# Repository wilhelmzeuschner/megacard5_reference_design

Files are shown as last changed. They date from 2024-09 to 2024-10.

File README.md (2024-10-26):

# Reference Design for MegaCard 5 Carrier Board
**Further documentation avaiable at: www.wizeus.de/megacard5-docs**
Reference design for the MegaCard 5 100 Mbit/s Ethernet Switch Carrier Board.

The design is done in KiCad. All KiCad files are included in this repo.

## PDF Schematic
The pdf schematic is available here: https://github.com/wilhelmzeuschner/megacard5_reference_design/blob/main/doc/megacard5_reference_design.pdf

## PCB images




Please note that the picture shows Rev. 1.0 of the PCB. The render shows Rev. 1.1.

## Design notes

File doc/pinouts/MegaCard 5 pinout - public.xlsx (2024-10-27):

MegaCard 5 Top Side Pins |  |  | MegaCard 5 Bottom Side Pins
Pin number | Function | Note | Pin number | Function | Note
1 | GND |  | 2 | GND
3 | PWR_IN | Power input | 4 | !RESET | ETH switch IC reset signal (active low, can be left floating)
5 | PWR_IN | Power input | 6 | !POWER_OFF | ETH switch IC power down signal (active low, can be left floating)
7 | GND |  | 8 | GND
9 | 5V_OUT | 5 V output / input | 10 | RESERVED | Don't connect on host PCB
11 | 5V_OUT | 5 V output / input | 12 | SCL/MDC | Optional configuration interface clock signal
13 | 3.3V_OUT | 3.3 V output / input | 14 | SDA/MDIO | Optional configuration interface data signal
15 | GND |  | 16 | GND
MegaCard 5 Alignment slot in PCB / Connector |  |  | MegaCard 5 Alignment slot in PCB / Connector
17 | RESERVED | Don't connect on host PCB | 18 | RESERVED | Don't connect on host PCB
19 | RESERVED | Don't connect on host PCB | 20 | RESERVED | Don't connect on host PCB
21 | GND |  | 22 | GND
23 | P0_RX+ |  | 24 | P3_RX+
25 | P0_RX- |  | 26 | P3_RX-
27 | GND |  | 28 | GND
29 | P0_TX+ |  | 30 | P3_TX+
31 | P0_TX- |  | 32 | P3_TX-
33 | GND |  | 34 | GND
35 | P1_RX+ |  | 36 | P4_RX+
37 | P1_RX- |  | 38 | P4_RX-
39 | GND |  | 40 | GND
41 | P1_TX+ |  | 42 | P4_TX+
43 | P1_TX- |  | 44 | P4_TX-
45 | GND |  | 46 | GND
47 | P2_RX+ |  | 48 | P2_TX+
49 | P2_RX- |  | 50 | P2_TX-
51 | GND |  | 52 | GND
 |  |  |  |  |  | https://www.te.com/commerce/DocumentDelivery/DDEController?Action=showdoc

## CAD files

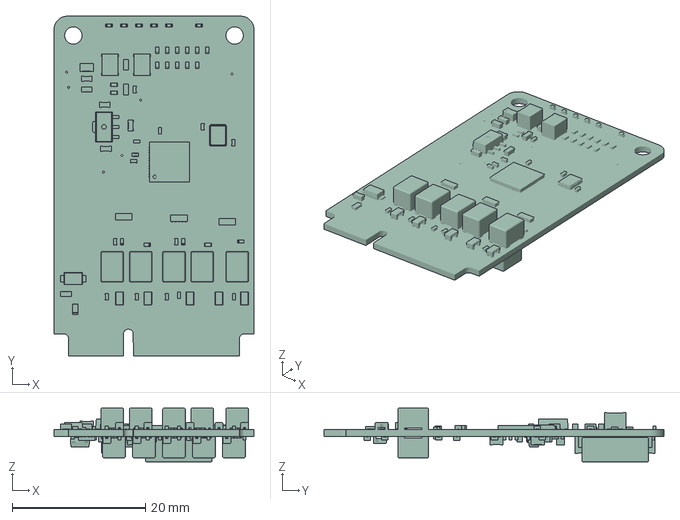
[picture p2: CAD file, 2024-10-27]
cad/MegaCard 5 3D printable model.3mf
30.0 x 51.0 x 8.09 mm

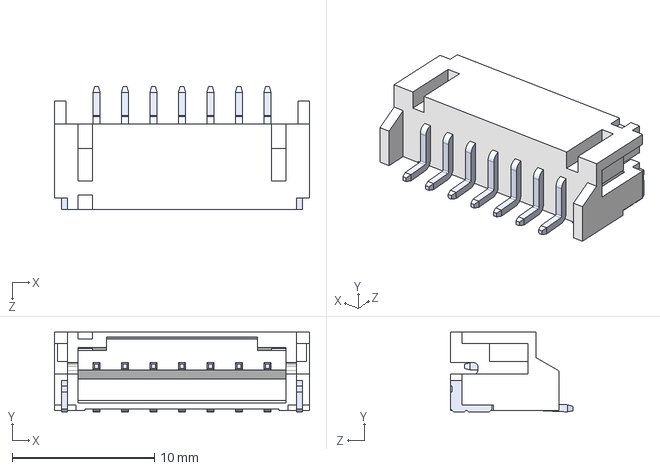
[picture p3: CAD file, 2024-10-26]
pcb/kicad_3d_models/S7B-PH-SM4-TB.STEP
17.9 x 5.60 x 8.60 mm

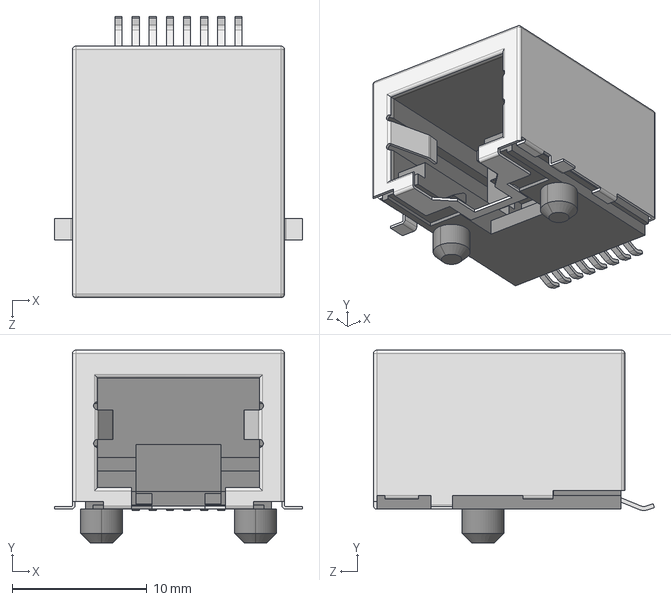
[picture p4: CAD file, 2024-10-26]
pcb/kicad_3d_models/MJ88-B211-JRS3.step
18.4 x 14.3 x 20.9 mm

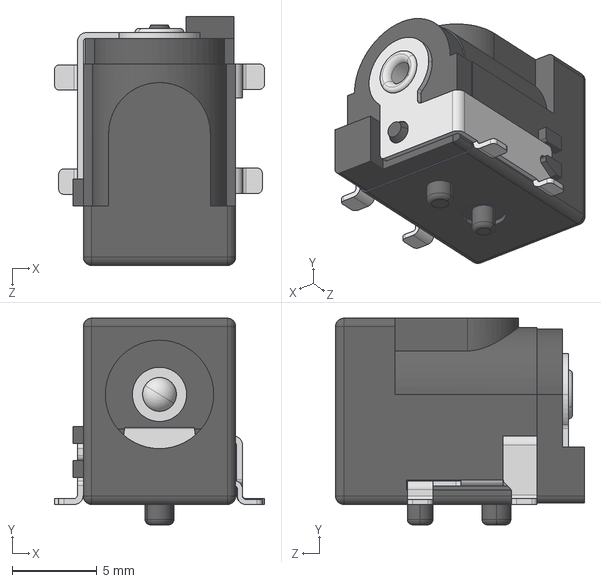
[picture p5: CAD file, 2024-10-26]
pcb/kicad_3d_models/DC-005-5A-2-0-SMT.step
12.4 x 12.2 x 14.7 mm

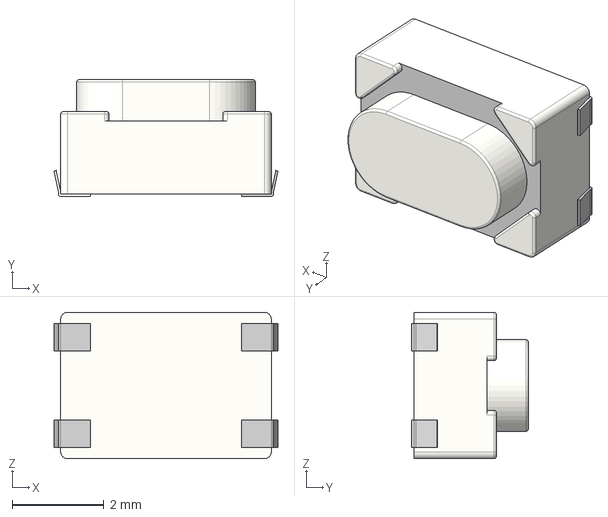
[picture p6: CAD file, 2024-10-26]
pcb/kicad_3d_models/SKRPAC.STEP
4.89 x 2.55 x 3.20 mm

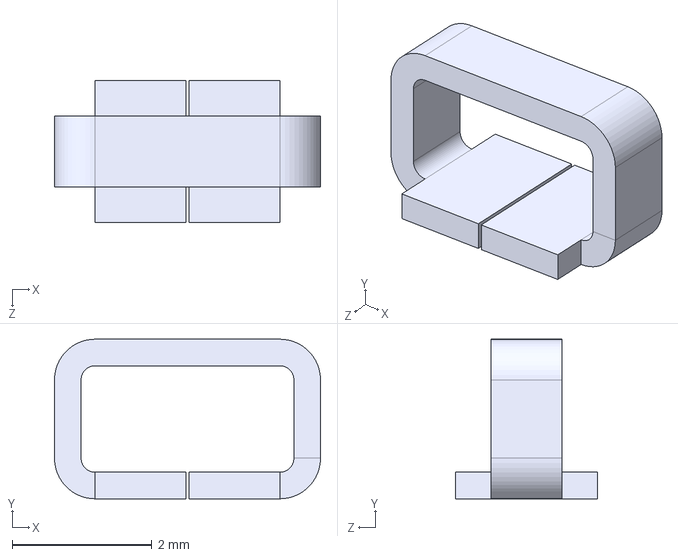
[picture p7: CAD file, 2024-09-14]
pcb/kicad_3d_models/5019.step
3.81 x 2.29 x 2.03 mm

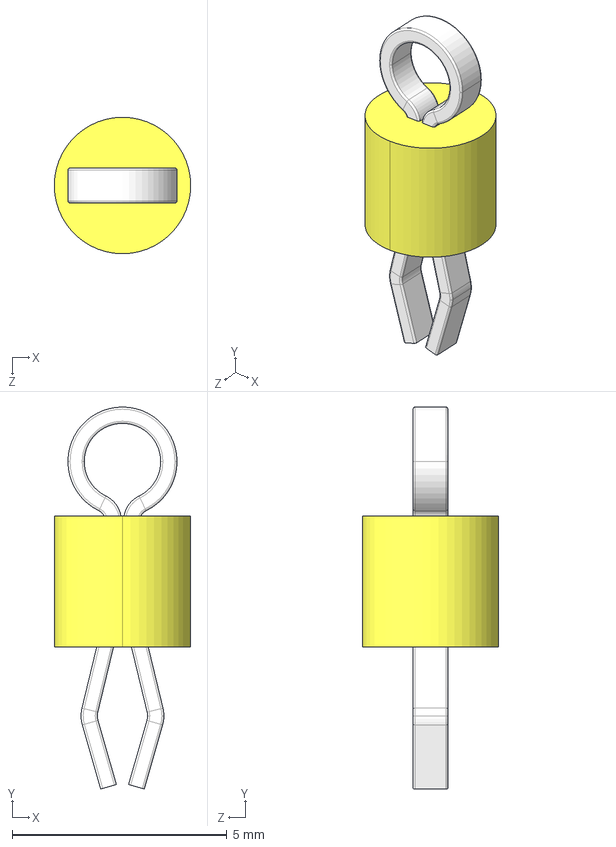
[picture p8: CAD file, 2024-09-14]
pcb/kicad_3d_models/5009.step
3.17 x 8.89 x 3.17 mm

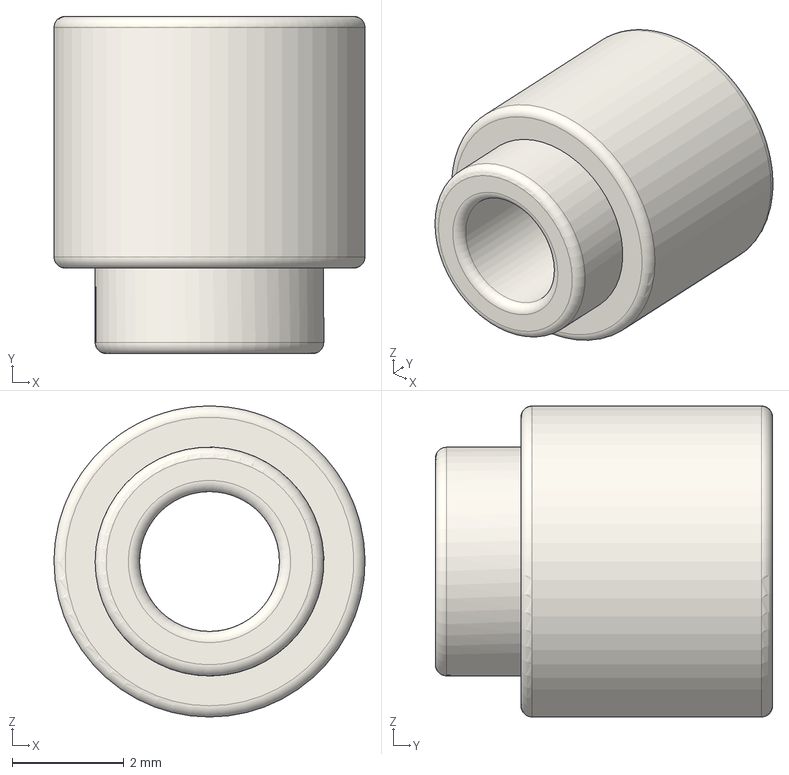
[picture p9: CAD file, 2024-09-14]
pcb/kicad_3d_models/SMTSO2545CTJ.step
5.56 x 6.03 x 5.56 mm

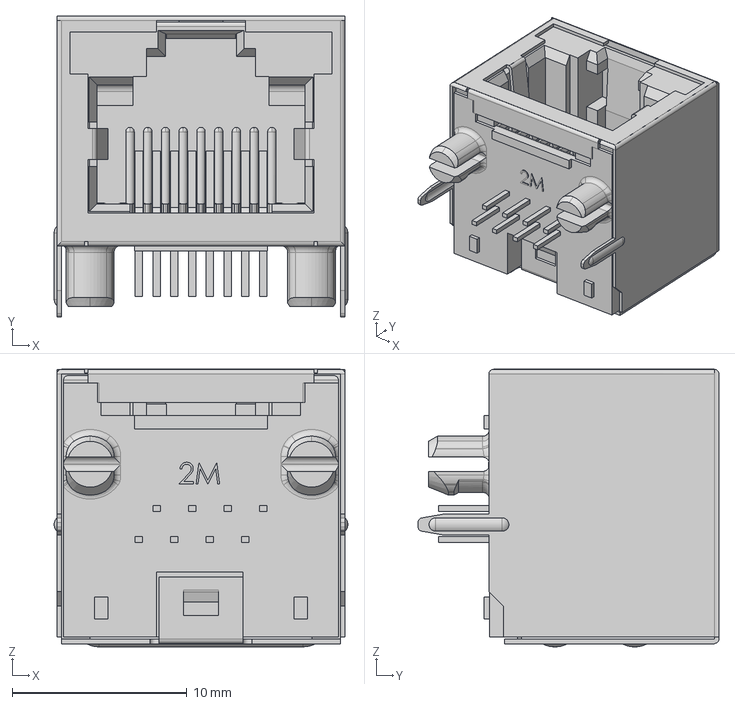
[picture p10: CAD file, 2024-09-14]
pcb/kicad_3d_models/ethernet_connector.STEP
16.8 x 17.2 x 15.9 mm

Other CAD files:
pcb/kicad_3d_models/5007.step
pcb/kicad_3d_models/5006.step
pcb/kicad_3d_models/5005.step

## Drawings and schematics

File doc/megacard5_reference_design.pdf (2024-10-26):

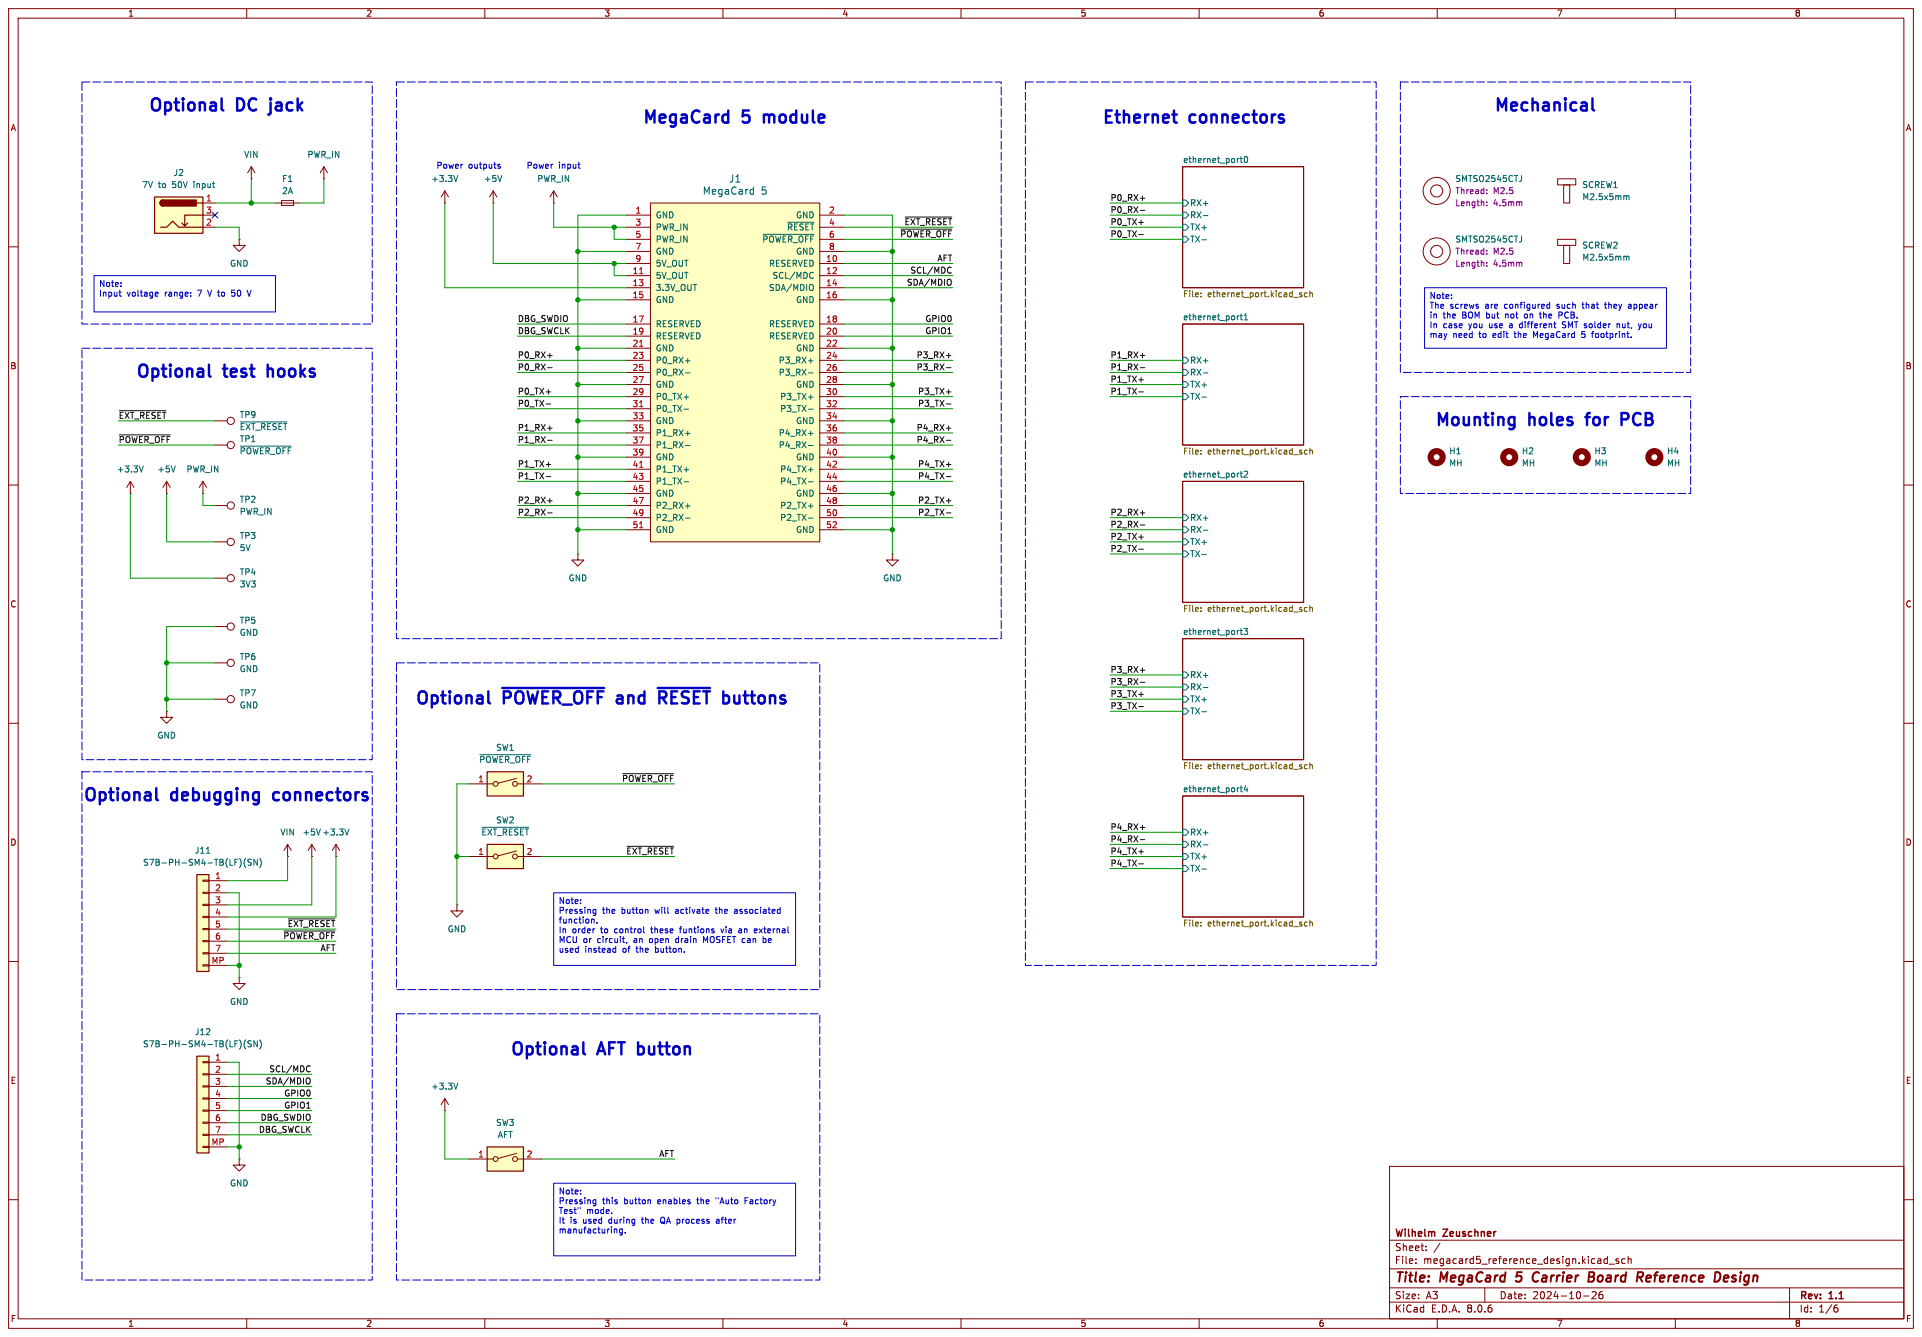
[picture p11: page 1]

Mechanical Ethernet connectors
TX+ TX- RX+ RX- ethernet_port0 File: ethernet_port.kicad_sch TX+ TX- RX+ RX- ethernet_port1 File: ethernet_port.kicad_sch TX+ TX- RX+ RX- ethernet_port2 File: ethernet_port.kicad_sch TX+ TX- RX+ RX- ethernet_port4 File: ethernet_port.kicad_sch TX+ TX- RX+ RX- ethernet_port3 File: ethernet_port.kicad_sch

in the BOM but not on the PCB.

Mounting holes for PCB

Optional ~{POWER_OFF}and ~{RESET}buttons

J11 S7B-PH-SM4-TB(LF)(SN) GND

used instead of the button. Note: Pressing this button enables the "Auto Factory Test" mode.

SCL/MDC GPIO1 SDA/MDIO

It is used during the QA process after manufacturing.

File: megacard5_reference_design.kicad_sch Sheet: / Wilhelm Zeuschner

Id: 1/6 Title: MegaCard 5 Carrier Board Reference Design

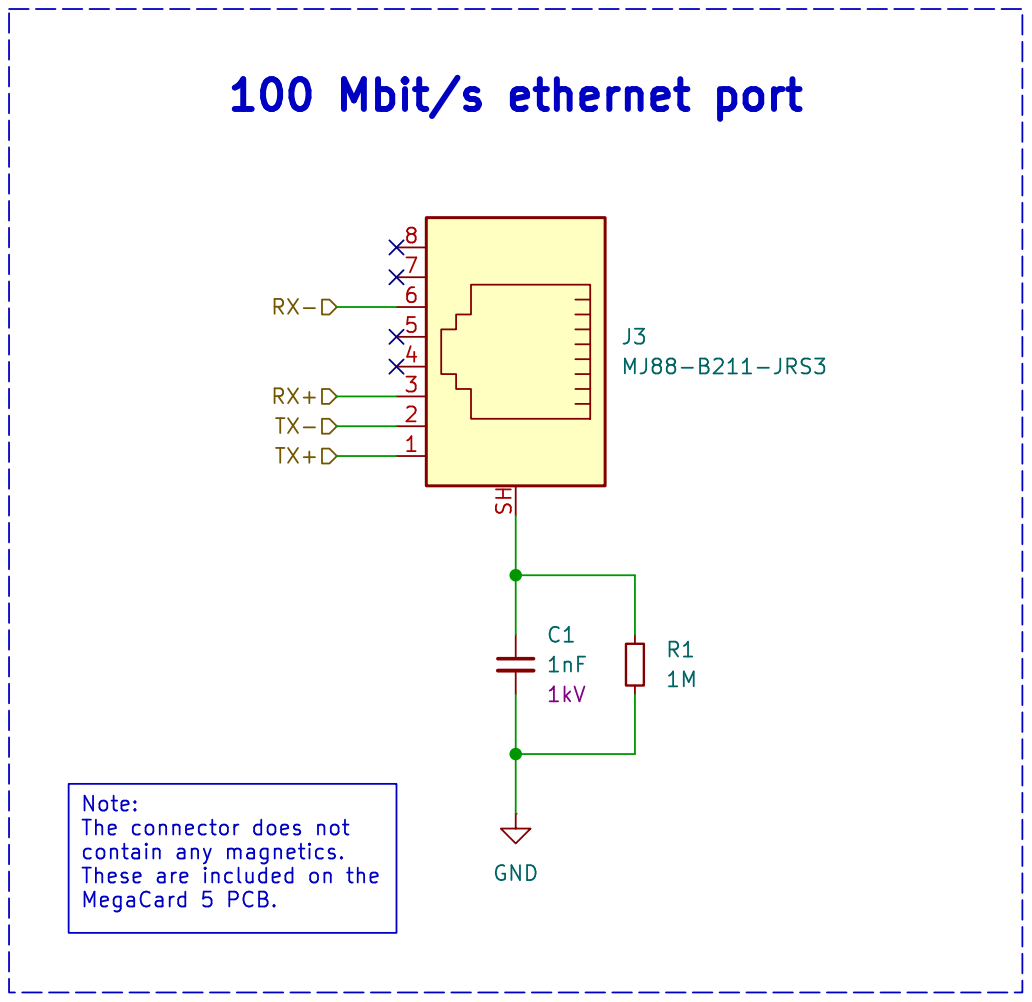
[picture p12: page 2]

Id: 2/6 Title: Ethernet port File: ethernet_port.kicad_sch Sheet: /ethernet_port0/ Wilhelm Zeuschner

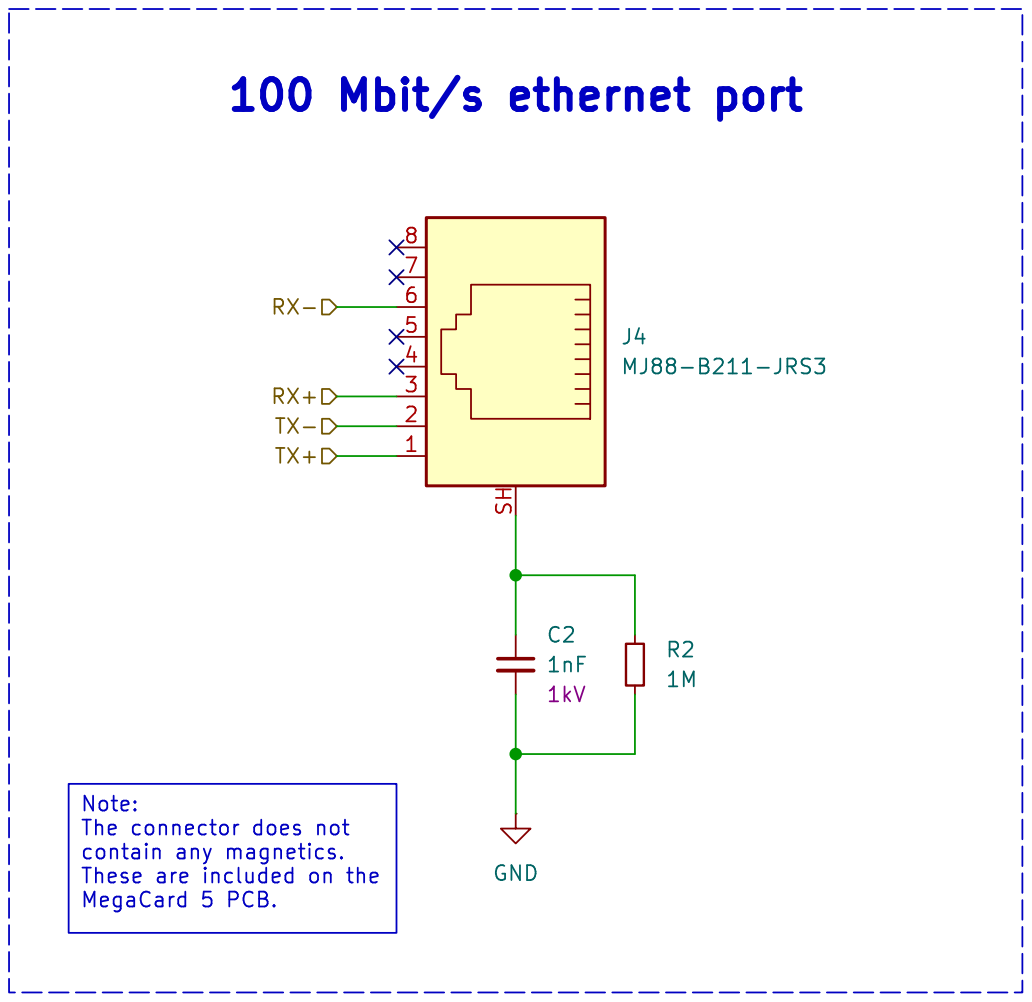
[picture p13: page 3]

Id: 3/6 Title: Ethernet port File: ethernet_port.kicad_sch Sheet: /ethernet_port1/ Wilhelm Zeuschner

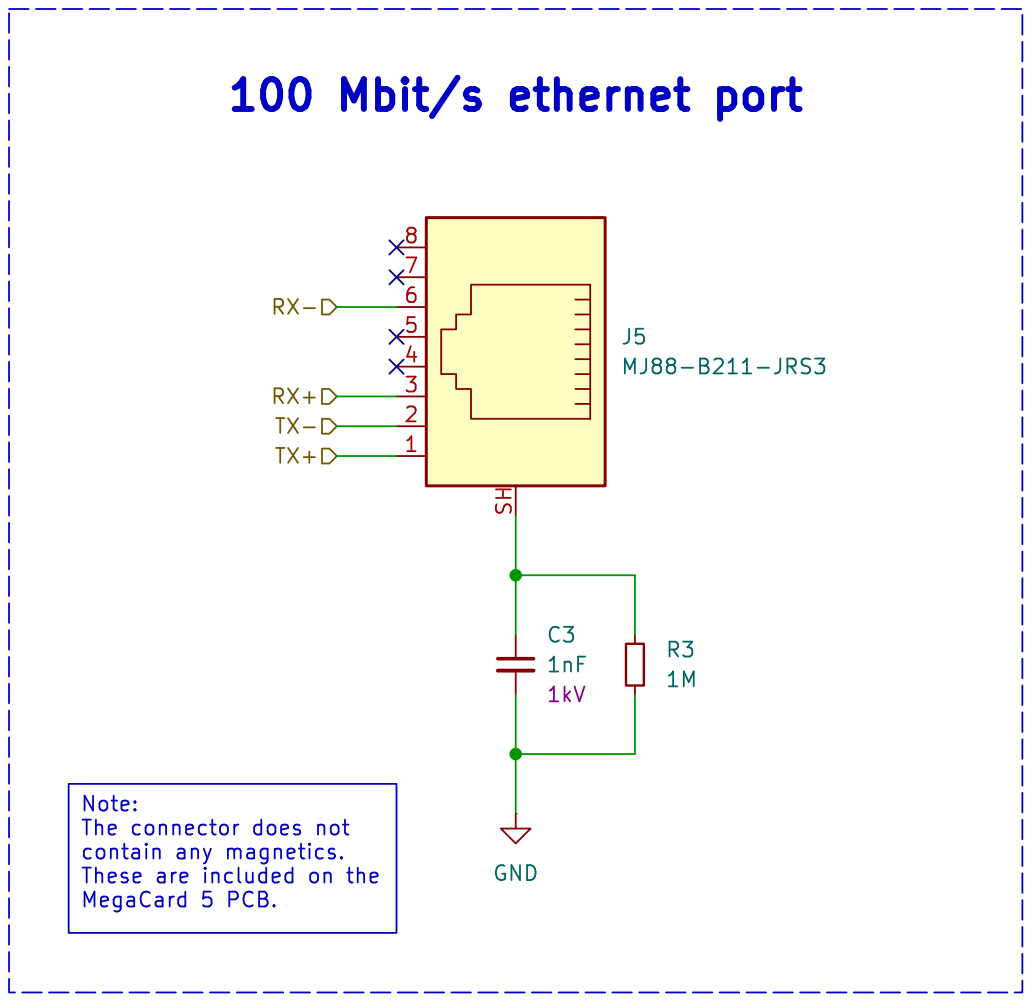
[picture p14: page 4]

Id: 4/6 Title: Ethernet port File: ethernet_port.kicad_sch Sheet: /ethernet_port2/ Wilhelm Zeuschner

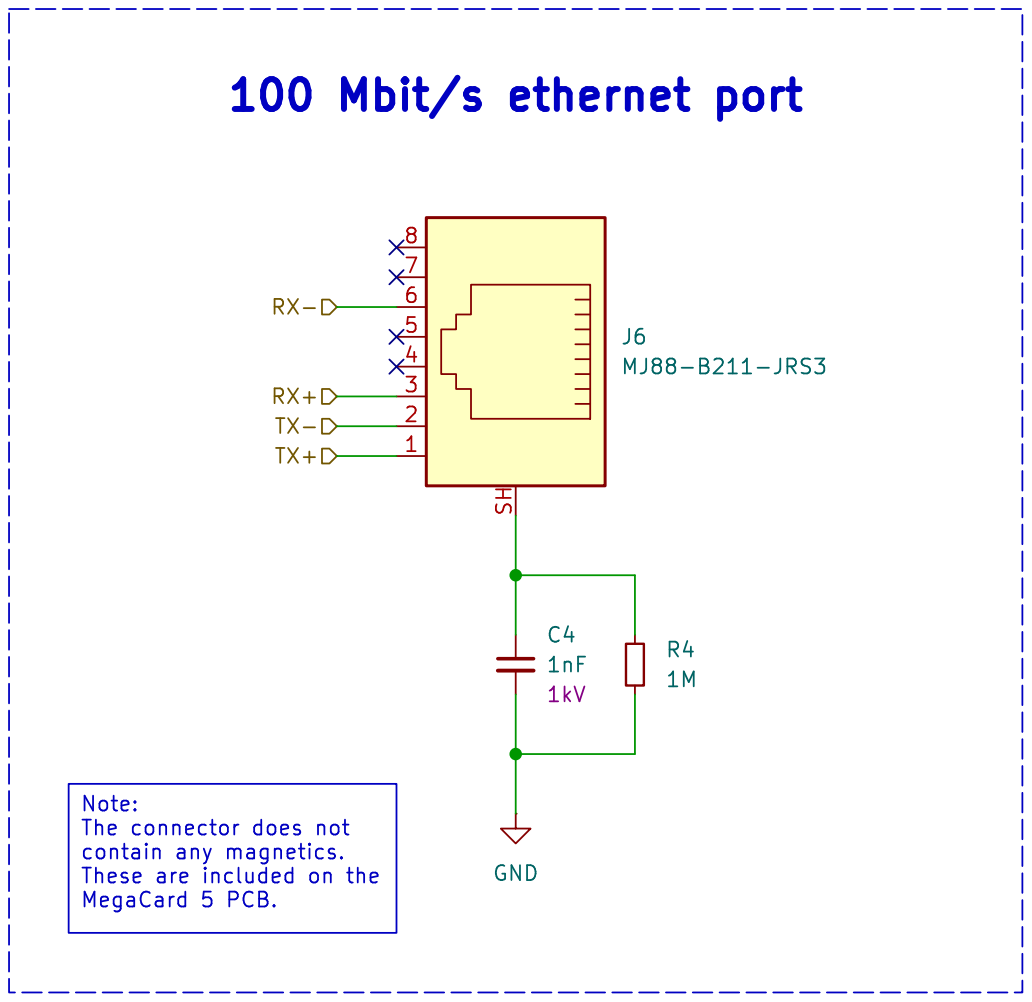
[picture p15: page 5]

Id: 5/6 Title: Ethernet port File: ethernet_port.kicad_sch Sheet: /ethernet_port3/ Wilhelm Zeuschner

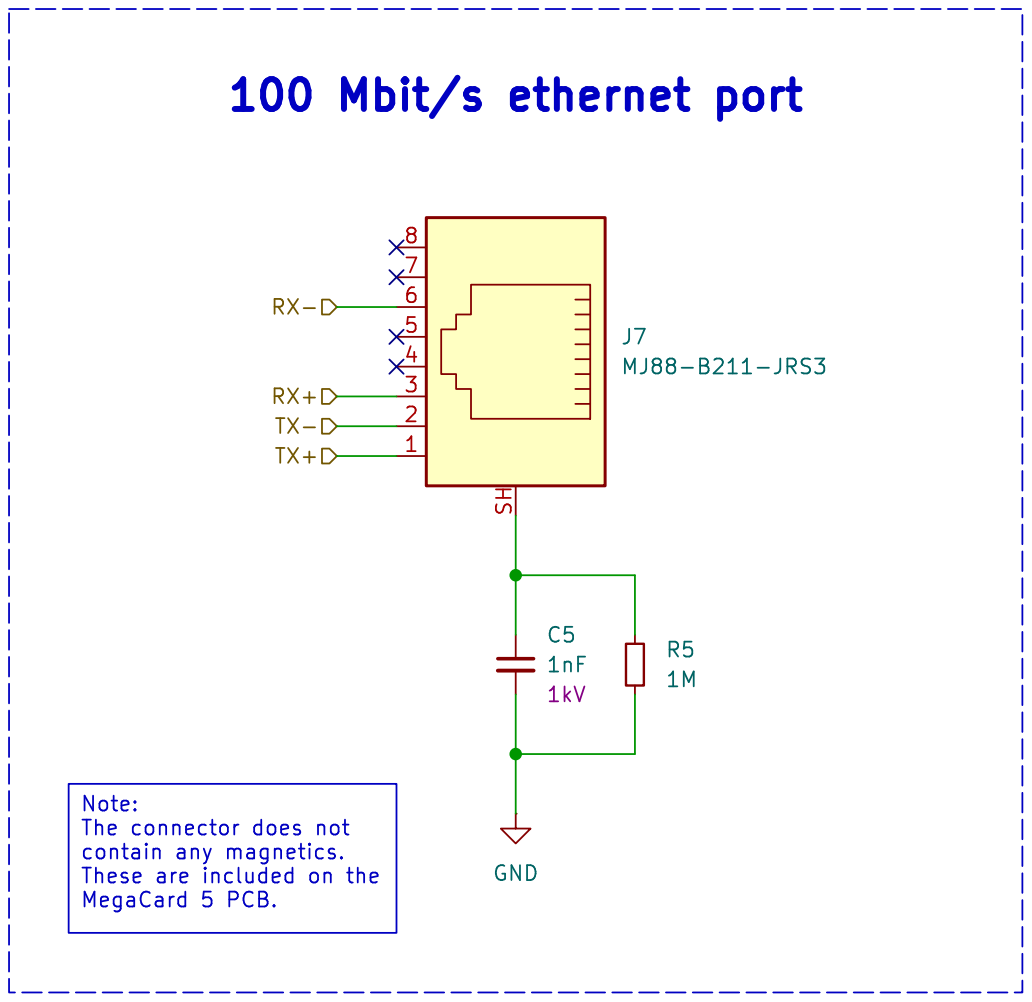
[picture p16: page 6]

Id: 6/6 Title: Ethernet port File: ethernet_port.kicad_sch Sheet: /ethernet_port4/ Wilhelm Zeuschner

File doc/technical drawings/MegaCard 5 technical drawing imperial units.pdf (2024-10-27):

# Bottom view

# 1.18in 2.01in 1.88in 0.04in⁺⁰.05in -0in

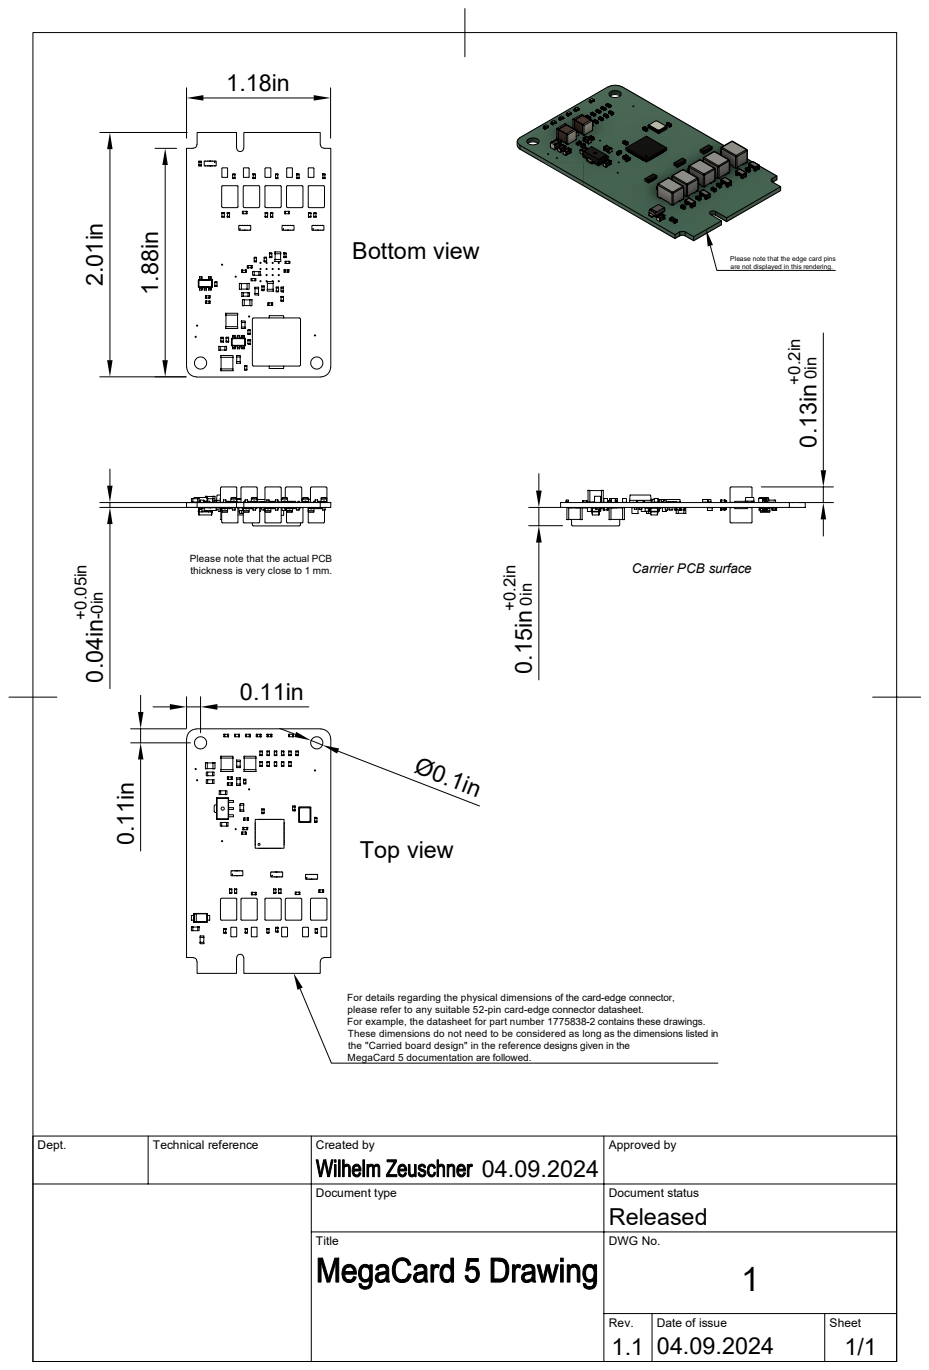
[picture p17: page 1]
Dept.; Technical reference; Created by; Approved by; Document type; Document status; Title; DWG No.; Rev.; Date of issue; Sheet; Released; Top view

Please note that the edge card pins
are not displayed in this rendering.

Please note that the actual PCB
thickness is very close to 1 mm.

Carrier PCB surface

For details regarding the physical dimensions of the card-edge connector,
please refer to any suitable 52-pin card-edge connector datasheet.
For example, the datasheet for part number 1775838-2 contains these drawings.
These dimensions do not need to be considered as long as the dimensions listed in
the "Carried board design" in the reference designs given in the
MegaCard 5 documentation are followed.

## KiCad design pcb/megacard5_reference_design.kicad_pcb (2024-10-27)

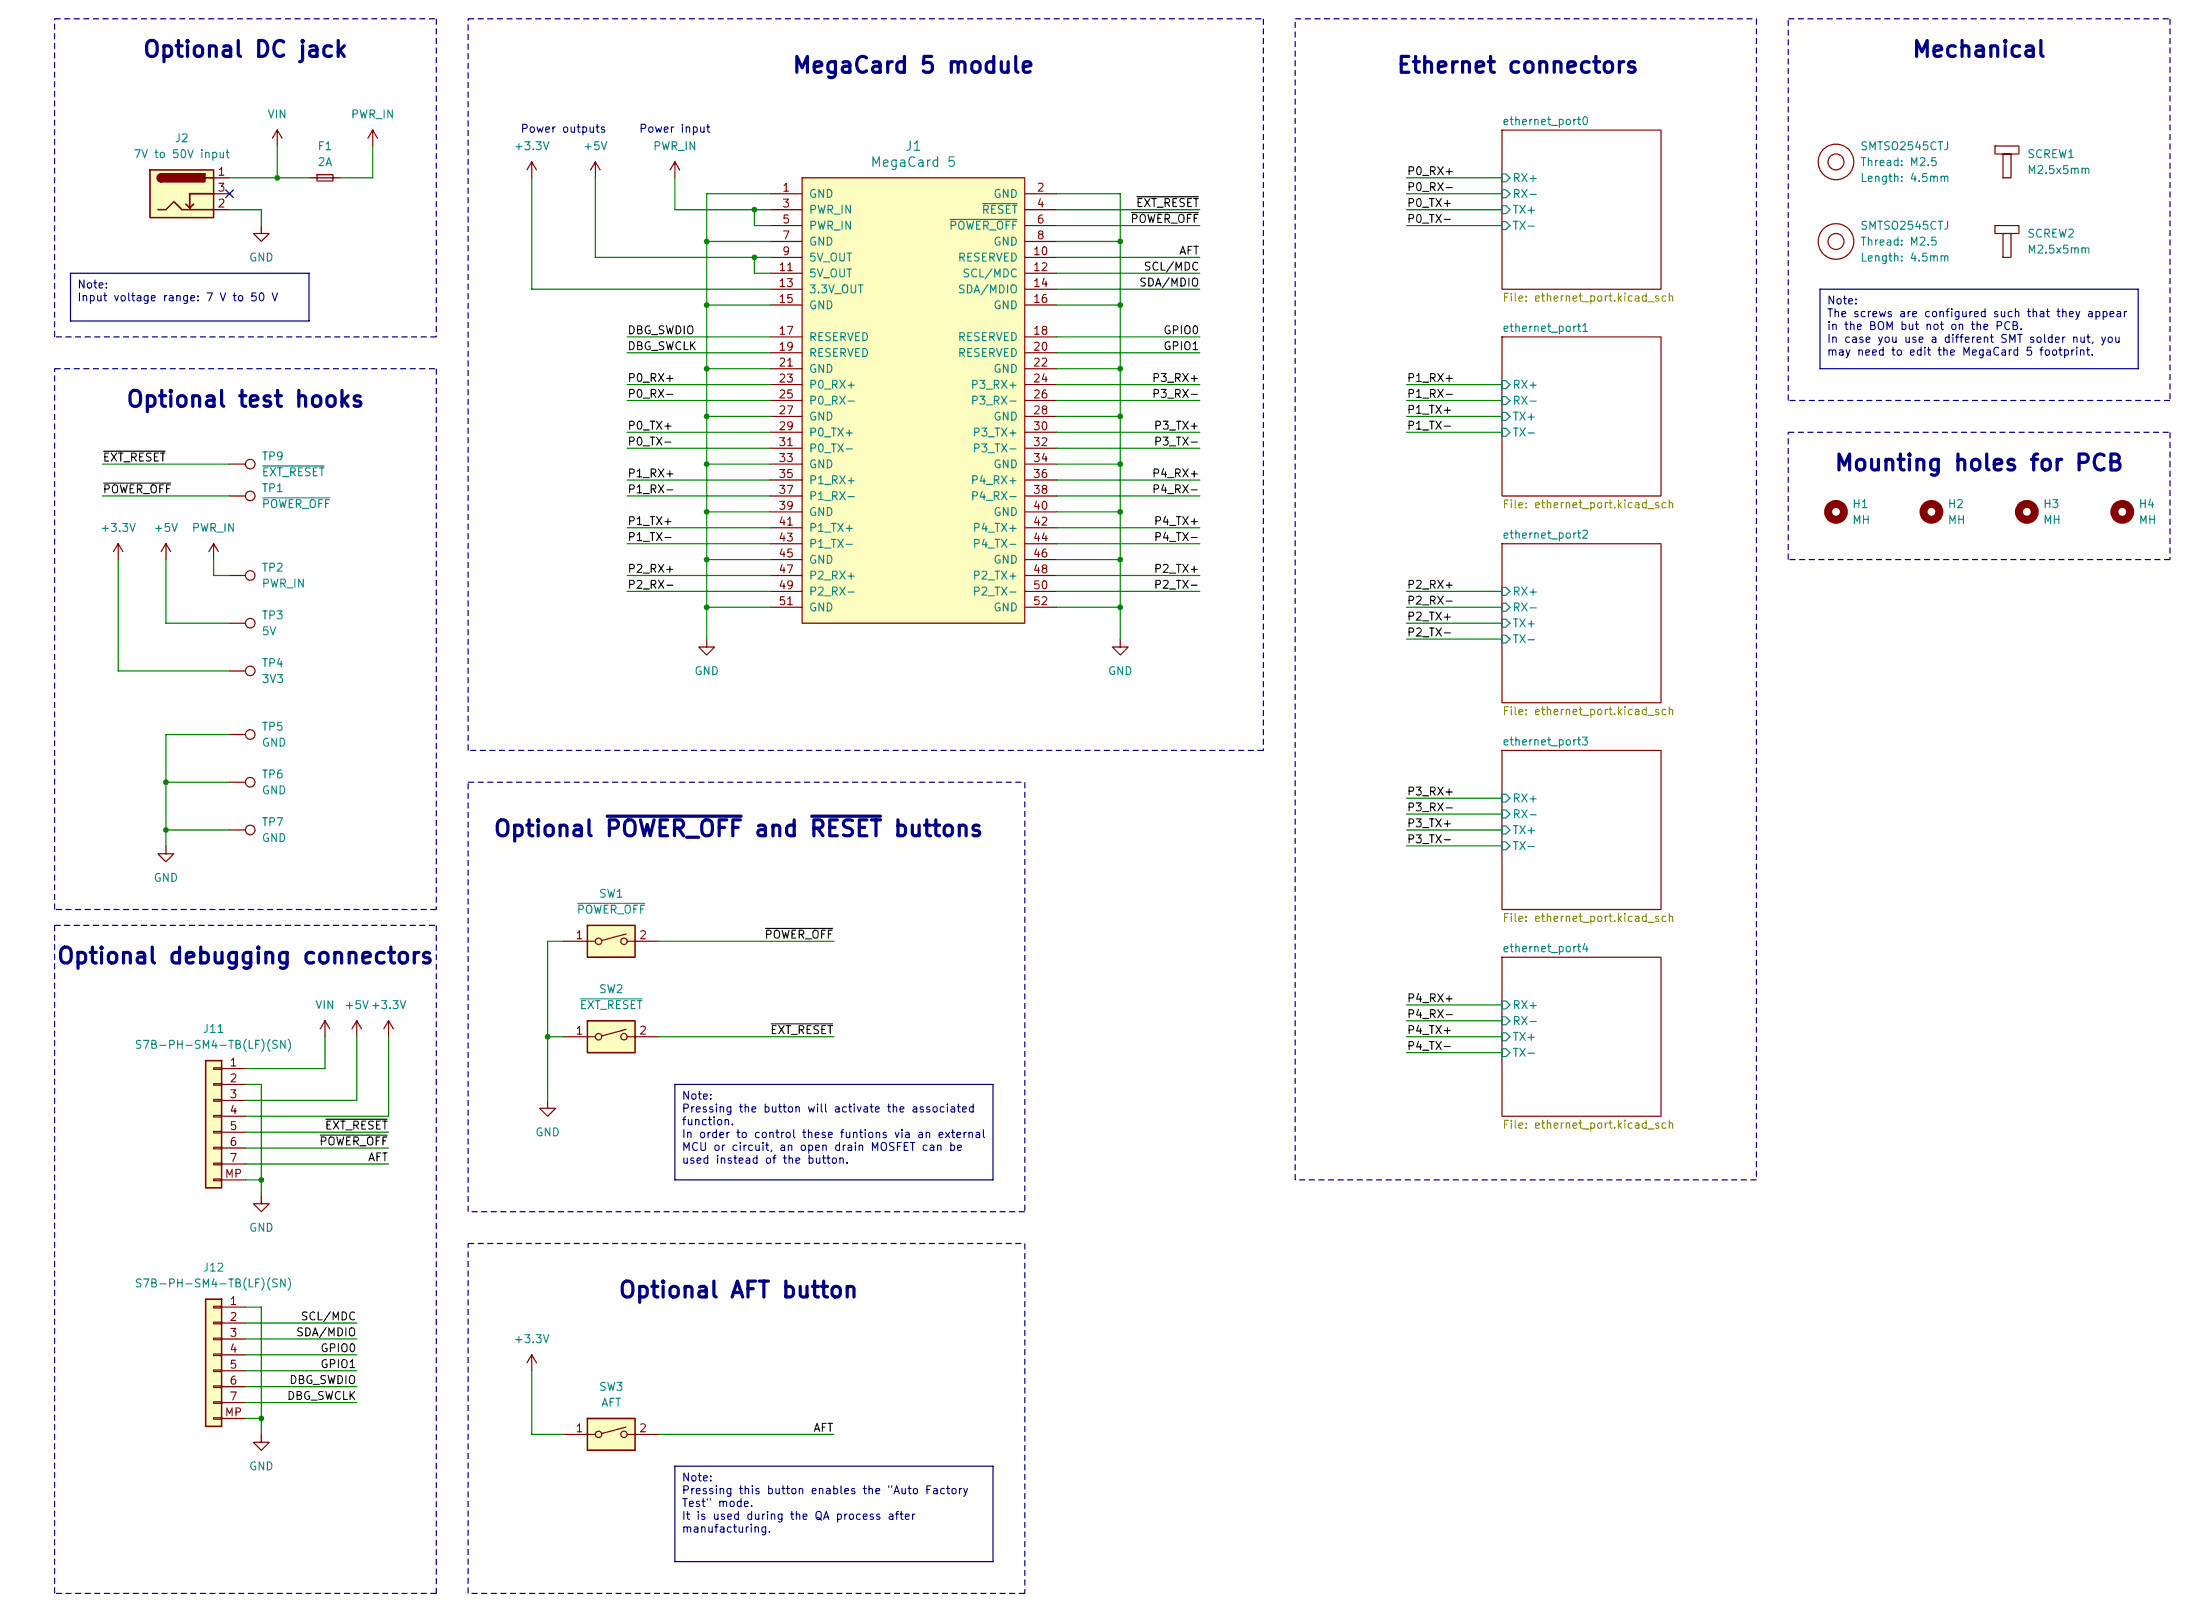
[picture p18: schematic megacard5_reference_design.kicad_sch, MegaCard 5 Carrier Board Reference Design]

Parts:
F1: 2A; Fuse_1206_3216Metric; LCSC PN C3105
H1, H2, H3, H4: MH; MountingHole_3.2mm_M3_DIN965
J1: MegaCard 5; MegaCard_5; LCSC PN C428485
J2: 7V to 50V input; DC-005-5A-2.0-SMT; LCSC PN C319134
J10, J13: SMTSO2545CTJ; LCSC PN C2916325
J11, J12: S7B-PH-SM4-TB(LF)(SN); JST_PH_S7B-PH-SM4-TB_1x07-1MP_P2.00mm_Horizontal; LCSC PN C265453
SCREW1, SCREW2: M2.5x5mm; LCSC PN C5183547
SW1: ~{POWER_OFF}; SKRPACE010; LCSC PN C139797
SW2: ~{EXT_RESET}; SKRPACE010; LCSC PN C139797
SW3: AFT; SKRPACE010; LCSC PN C139797
TP1: ~{POWER_OFF}; 5019; LCSC PN C5199800
TP2: PWR_IN; 5019; LCSC PN C5199800
TP3: 5V; 5019; LCSC PN C5199800
TP4: 3V3; 5019; LCSC PN C5199800
TP5, TP6, TP7: GND; 5019; LCSC PN C5199800
TP9: ~{EXT_RESET}; 5019; LCSC PN C5199800

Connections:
+3.3V: J1.13 (3.3V_OUT), J11.4, SW3.1, TP4.1
+5V: J1.9 (5V_OUT), J1.11 (5V_OUT), J11.3, TP3.1
/AFT: J1.10 (RESERVED), J11.7, SW3.2
/DBG_SWCLK: J1.19 (RESERVED), J12.7
/DBG_SWDIO: J1.17 (RESERVED), J12.6
/GPIO0: J1.18 (RESERVED), J12.4
/GPIO1: J1.20 (RESERVED), J12.5
/P0_RX+: J1.23 (P0_RX+); also elsewhere on the board
/P0_RX-: J1.25 (P0_RX-); also elsewhere on the board
/P0_TX+: J1.29 (P0_TX+); also elsewhere on the board
/P0_TX-: J1.31 (P0_TX-); also elsewhere on the board
/P1_RX+: J1.35 (P1_RX+); also elsewhere on the board
/P1_RX-: J1.37 (P1_RX-); also elsewhere on the board
/P1_TX+: J1.41 (P1_TX+); also elsewhere on the board
/P1_TX-: J1.43 (P1_TX-); also elsewhere on the board
/P2_RX+: J1.47 (P2_RX+); also elsewhere on the board
/P2_RX-: J1.49 (P2_RX-); also elsewhere on the board
/P2_TX+: J1.48 (P2_TX+); also elsewhere on the board
/P2_TX-: J1.50 (P2_TX-); also elsewhere on the board
/P3_RX+: J1.24 (P3_RX+); also elsewhere on the board
/P3_RX-: J1.26 (P3_RX-); also elsewhere on the board
/P3_TX+: J1.30 (P3_TX+); also elsewhere on the board
/P3_TX-: J1.32 (P3_TX-); also elsewhere on the board
/P4_RX+: J1.36 (P4_RX+); also elsewhere on the board
/P4_RX-: J1.38 (P4_RX-); also elsewhere on the board
/P4_TX+: J1.42 (P4_TX+); also elsewhere on the board
/P4_TX-: J1.44 (P4_TX-); also elsewhere on the board
/SCL/MDC: J1.12 (SCL/MDC), J12.2
/SDA/MDIO: J1.14 (SDA/MDIO), J12.3
/~EXT_RESET: J1.4 (~RESET), J11.5, SW2.2, TP9.1
/~POWER_OFF: J1.6 (~POWER_OFF), J11.6, SW1.2, TP1.1
GND: J1.1 (GND), J1.2 (GND), J1.7 (GND), J1.8 (GND), J1.15 (GND), J1.16 (GND), J1.21 (GND), J1.22 (GND), J1.27 (GND), J1.28 (GND), J1.33 (GND), J1.34 (GND), J1.39 (GND), J1.40 (GND), J1.45 (GND), J1.46 (GND), J1.51 (GND), J1.52 (GND), J2.2, J11.2, J11.MP, J12.1, J12.MP, SW1.1, SW2.1, TP5.1, TP6.1, TP7.1; also elsewhere on the board
PWR_IN: F1.2, J1.3 (PWR_IN), J1.5 (PWR_IN), TP2.1
VIN: F1.1, J2.1, J11.1

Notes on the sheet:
Note: Pressing the button will activate the associated function. In order to control these funtions via an external MCU or circuit, an open drain MOSFET can be used instead of the button.
Note: The screws are configured such that they appear in the BOM but not on the PCB. In case you use a different SMT solder nut, you may need to edit the MegaCard 5 footprint.
Note: Input voltage range: 7 V to 50 V
Note: Pressing this button enables the "Auto Factory Test" mode. It is used during the QA process after manufacturing.
Optional debugging connectors
Optional ~{POWER_OFF} and ~{RESET} buttons
Power input
Optional DC jack
Ethernet connectors
Mechanical
Mounting holes for PCB
MegaCard 5 module
Optional AFT button
Power outputs
Optional test hooks

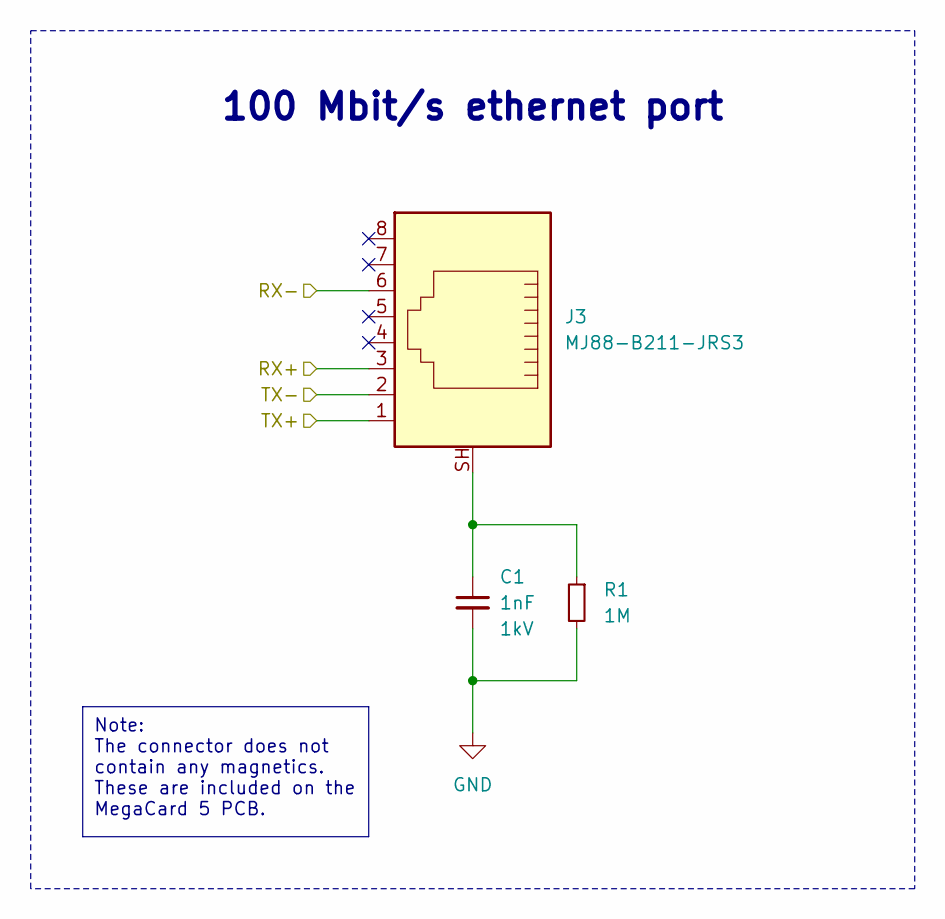
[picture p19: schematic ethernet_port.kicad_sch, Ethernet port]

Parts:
C1: 1nF; C_1206_3216Metric; Voltage 1kV; LCSC PN C23631
J3: MJ88-B211-JRS3; LCSC PN C2895614
R1: 1M; R_1206_3216Metric; LCSC PN C148194

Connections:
/P0_RX+: J3.3; also elsewhere on the board
/P0_RX-: J3.6; also elsewhere on the board
/P0_TX+: J3.1; also elsewhere on the board
/P0_TX-: J3.2; also elsewhere on the board
GND: C1.2, R1.2; also elsewhere on the board
unnamed: C1.1, J3.SH, R1.1

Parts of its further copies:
C2, C3, C4, C5: 1nF; C_1206_3216Metric; Voltage 1kV; LCSC PN C23631
J4, J5, J6, J7: MJ88-B211-JRS3; LCSC PN C2895614
R2, R3, R4, R5: 1M; R_1206_3216Metric; LCSC PN C148194

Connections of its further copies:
/P1_RX+: J4.3; also elsewhere on the board
/P1_RX-: J4.6; also elsewhere on the board
/P1_TX+: J4.1; also elsewhere on the board
/P1_TX-: J4.2; also elsewhere on the board
/P2_RX+: J5.3; also elsewhere on the board
/P2_RX-: J5.6; also elsewhere on the board
/P2_TX+: J5.1; also elsewhere on the board
/P2_TX-: J5.2; also elsewhere on the board
/P3_RX+: J6.3; also elsewhere on the board
/P3_RX-: J6.6; also elsewhere on the board
/P3_TX+: J6.1; also elsewhere on the board
/P3_TX-: J6.2; also elsewhere on the board
/P4_RX+: J7.3; also elsewhere on the board
/P4_RX-: J7.6; also elsewhere on the board
/P4_TX+: J7.1; also elsewhere on the board
/P4_TX-: J7.2; also elsewhere on the board
GND: C2.2, C3.2, C4.2, C5.2, R2.2, R3.2, R4.2, R5.2; also elsewhere on the board
unnamed: C2.1, J4.SH, R2.1
unnamed: C3.1, J5.SH, R3.1
unnamed: C4.1, J6.SH, R4.1
unnamed: C5.1, J7.SH, R5.1

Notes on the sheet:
Note: The connector does not contain any magnetics. These are included on the MegaCard 5 PCB.
100 Mbit/s ethernet port

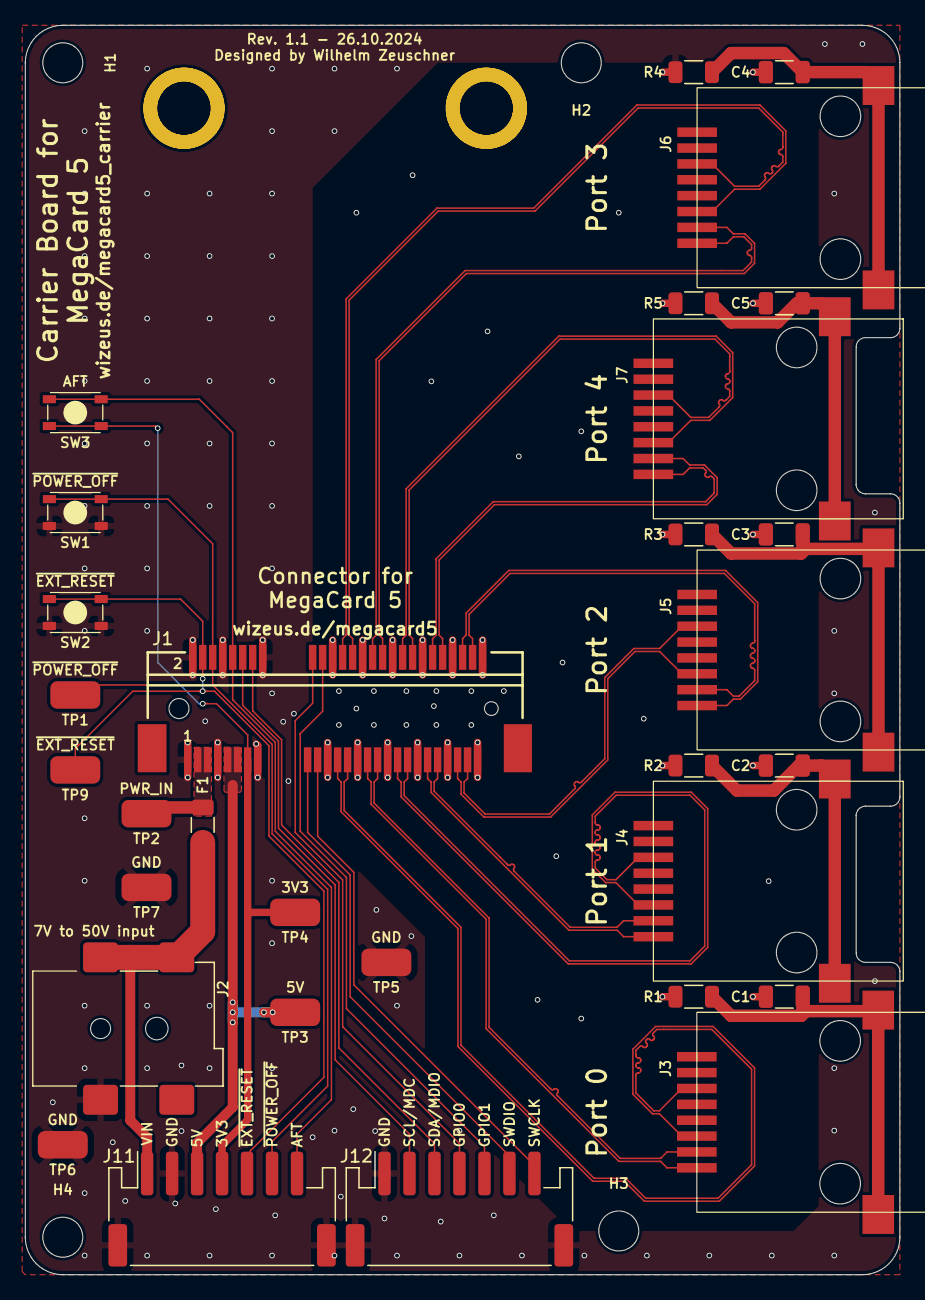
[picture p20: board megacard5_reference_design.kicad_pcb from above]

Board: 4 copper layers, 70.0 x 100.0 mm, 37 parts (0 on the bottom side), 39 nets.

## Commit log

2024-09-15 PCBs ordered v1.0
    [megacard5_reference_design-CuBottom.gbr, megacard5_reference_design-CuIn1.gbr, megacard5_reference_design-CuIn2.gbr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]
2024-10-26 updated PCB to Rev 1.1
    [DC-005-5A-2-0-SMT.step, MJ88-B211-JRS3.step, S7B-PH-SM4-TB.STEP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]
2024-10-26 added pdf schematic
2024-10-26 renamed VCC to PWR_IN
    [megacard5_reference_design.kicad_pcb, megacard5_reference_design.kicad_sch]
2024-10-27 update drawing
    [megacard5_reference_design.kicad_pcb]
2024-10-27 add 3D models
    [MegaCard 5 3D printable model.3mf]
2024-10-27 added pinouts
    [MegaCard 5 pinout - public.xlsx]
